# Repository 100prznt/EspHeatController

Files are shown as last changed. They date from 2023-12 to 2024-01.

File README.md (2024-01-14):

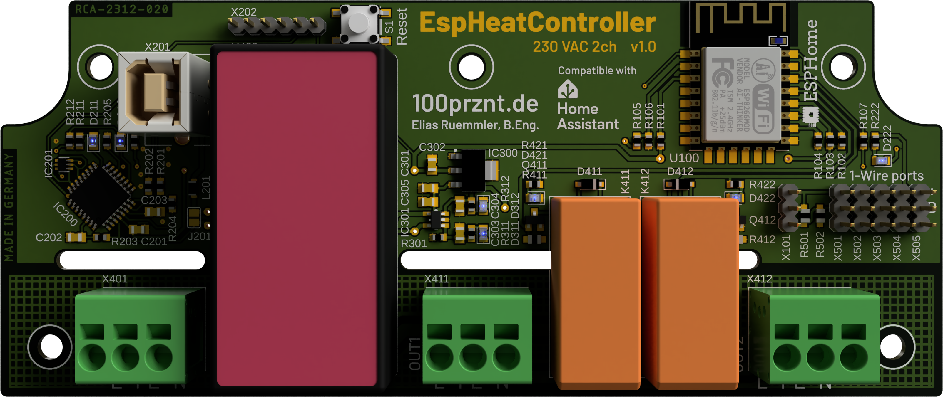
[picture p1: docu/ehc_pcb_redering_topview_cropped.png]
CAD rendering EspHeatController PCB


# HeatController
Bang-bang heat controller with 2 channels. ESP8266 based and compatible with Home Assistant.

## Specs
- ESP8266MOD (ESP-12-F)
- Onboard USB-UART bridge (FTDI)
- 230 VAC power supply with higher isolation voltage (for use in wet environment)
- Automatic switching of the power supply between USB and AC power
- Fully compatible with ESPHome and Home Assistant
- 2 output channels (230 VAC max. 10 A)
- 5 header for DS18B20 1-Wire temperature sensors
- Header for analog input

## Assembly
The PCB fits into a [Spelsberg TG PC 1612-9-to](https://www.spelsberg.de/industrieleergehaeuse/glatt-mit-befestigungsnocken/20100701/) enclosure. There is lots of space for the 230 V wiring in the lower area. I have installed PowerCon sockets from Neutrik here and M8 sockets for the DS818B20 sensors.

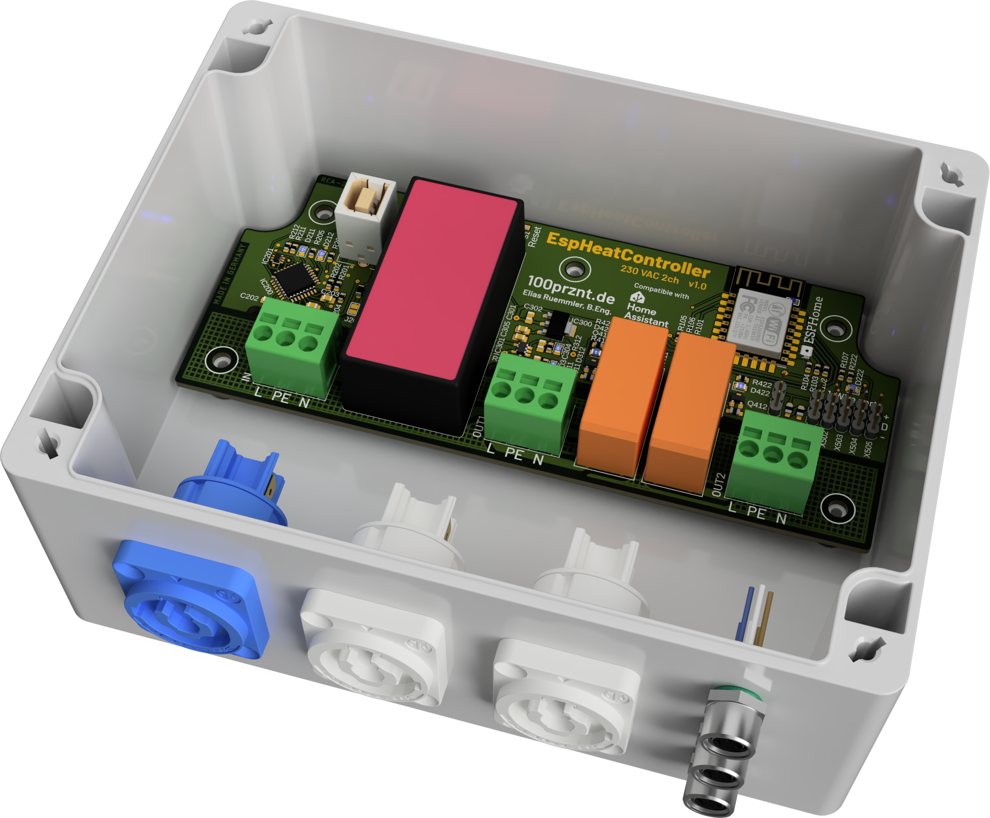
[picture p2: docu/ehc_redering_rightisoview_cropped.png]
CAD rendering EspHeatController


## Home Assistant

### Dashboard
The initial use of the __EspHeatController__ for me was as a frost watcher in addition to a pipe heating system. I created a separate dashboard in Home Assistant for this use case.

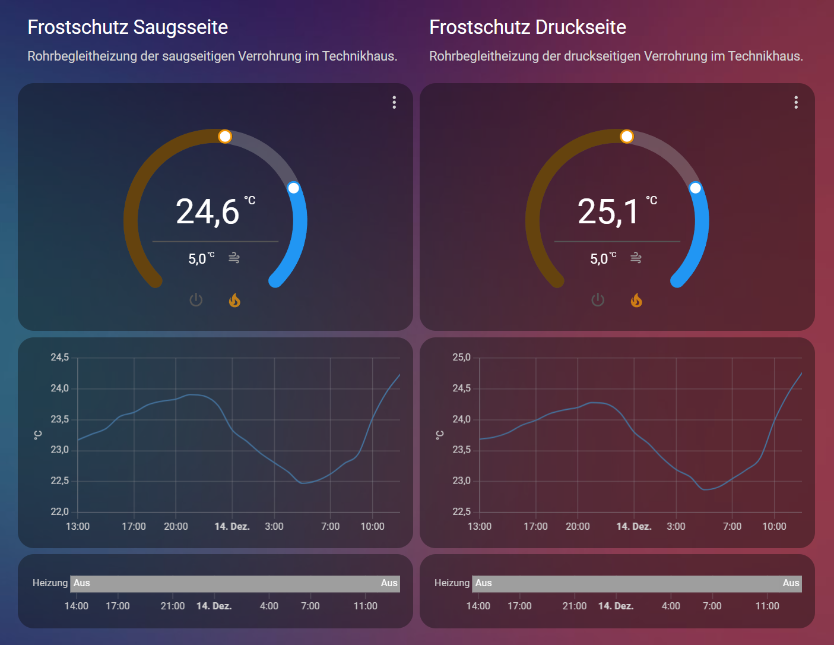
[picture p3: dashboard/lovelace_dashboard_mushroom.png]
Dashbord for the EspHeatController


You can find the configuration for this dashboard here:

* [dashboard/lovelace_ehc_config.yaml](dashboard/lovelace_ehc_config.yaml)

The following HACS extensions are required for this dashboard:

* [Mushroom](https://github.com/piitaya/lovelace-mushroom)
* [UI Card for Better Thermostat](https://github.com/KartoffelToby/better-thermostat-ui-card)

## Usage
As mentioned above, I use the __EspHeatController__ as a frost protector, the ESPHome config [esphome_ehc_config.yaml](esphome_ehc_config.yaml) implements a bang-bang controller for this. Alternatively, the hardware can be configured as a thermostat. It is also possible to control a cooling system in addition to the heater using the two switching channels.

## Function and description

### Datasheets
* [FTDI FT232BL](https://ftdichip.com/wp-content/uploads/2020/08/DS_FT232BL_BQ.pdf)
* [STMicroelectronics LD1117S](http://www.st.com/content/ccc/resource/technical/document/datasheet/99/3b/7d/91/91/51/4b/be/CD00000544.pdf/files/CD00000544.pdf/jcr:content/translations/en.CD0000054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)
* [TI TPS2104](https://www.ti.com/lit/gpn/tps2104)
* [Rohm UMH3N](https://fscdn.rohm.com/en/products/databook/datasheet/discrete/transistor/digital/umh3ntn-e.pdf)
* [AI Thinker ESP8266MOD](https://docs.ai-thinker.com/_media/esp8266/docs/esp-12f_product_specification_en.pdf)

## Hardware Versions
See [versions.md](versions.md) for hardware version details.

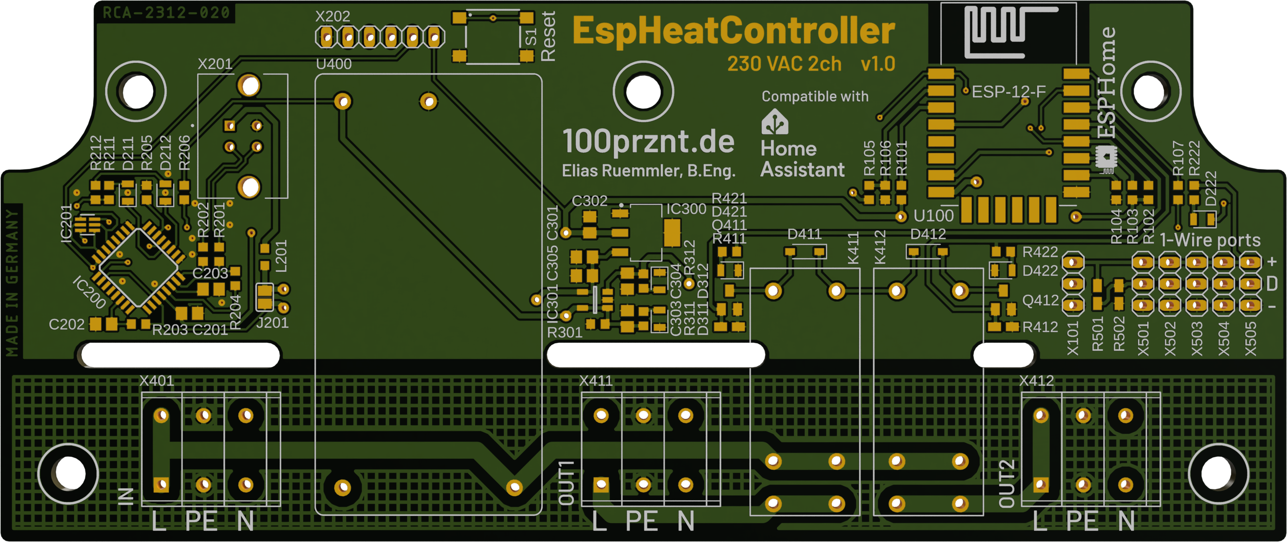
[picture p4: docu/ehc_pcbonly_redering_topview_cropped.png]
CAD rendering EspHeatController PCB w/o packages


### Known bugs in HW rev. v1.0
* [ ] Different resistor packages (R0603 vs. R0805W)
* [ ] IC301 invalide function table for USB power only
* [ ] IC300 (LD1117S) thermal != gnd
* [ ] IC200 (FT232BL) logiclevel for RST pin must be 5 V

### Features for next version
Features for new hardware versions.

* [ ] Onboard temperature sensor
* [ ] X202: Use stadard FTDI header pin assigment ([Datasheet TTL-232R](https://ftdichip.com/wp-content/uploads/2023/07/DS_TTL-232R_CABLES.pdf))
* [ ] Hardware lock between both relays (to use as 2-way motor switch)
* [ ] Hardware lock for the relays in boot state (check an [IO expander](https://esphome.io/#miscellaneous-components))
* [ ] Expand space between PE and GND
* [ ] Testpins for 5 V power supply
* [ ] Change FT232BL to [FT232RNL](https://ftdichip.com/wp-content/uploads/2023/03/DS_FT232RN.pdf) or external programmer

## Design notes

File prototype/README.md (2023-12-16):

# 1st Prototype

The idea to create the __EspHeatController__ was born out of necessity. Unexpectedly, winter was just around the corner and the pool water pipes were in risk of freezing. So the first __EspHeatController__ was created from the storage box.

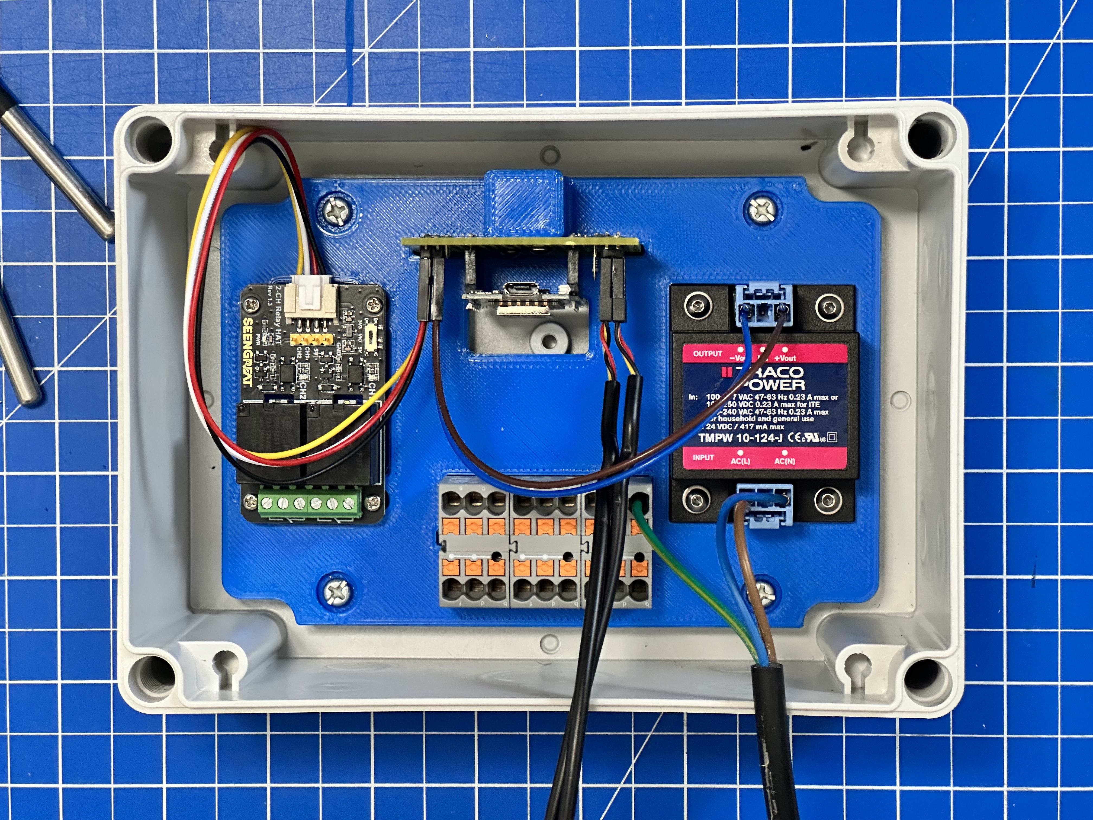
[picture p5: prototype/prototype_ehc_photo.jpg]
Prototype of the 1st EspHeatController


## BOM
* [Wemos - D1 mini](https://amzn.to/48l3Jik)
* [Seengreat - 2ch Relay Modul](https://amzn.to/3TtgmDJ) 3.3 / 5 V version
* [DS18B20 Sensor](https://amzn.to/48bSDw8)
* [Traco Power - TMP 10-105-J](https://www.tracopower.com/de/deu/model/tmpw-10-105-j)
* [3d printed mounting plate](Einsatz_TK_PC_1813_11_tm.stl)

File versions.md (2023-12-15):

# v1.0
- Initial version
- 1st PCBs ordered on December 15, 2023

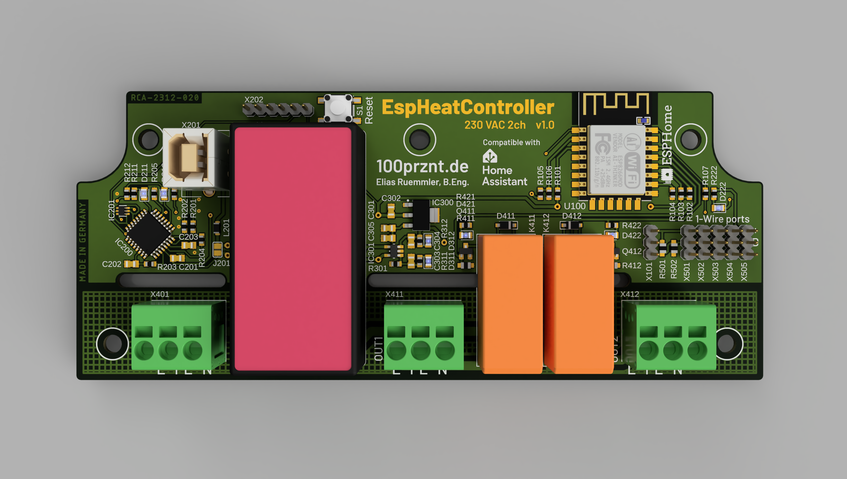
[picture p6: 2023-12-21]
docu/ehc_pcb_redering_topview.png

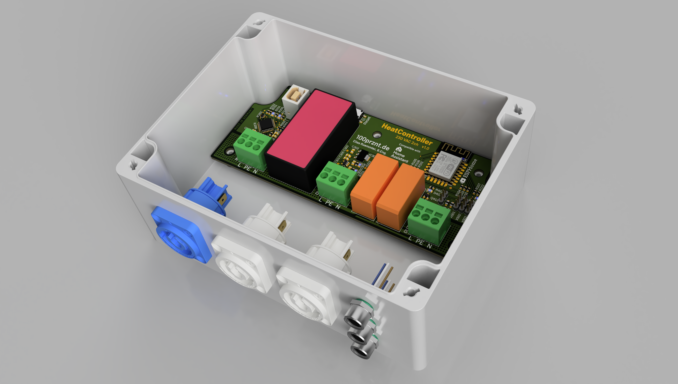
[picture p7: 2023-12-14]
docu/ehc_redering_rightisoview.png

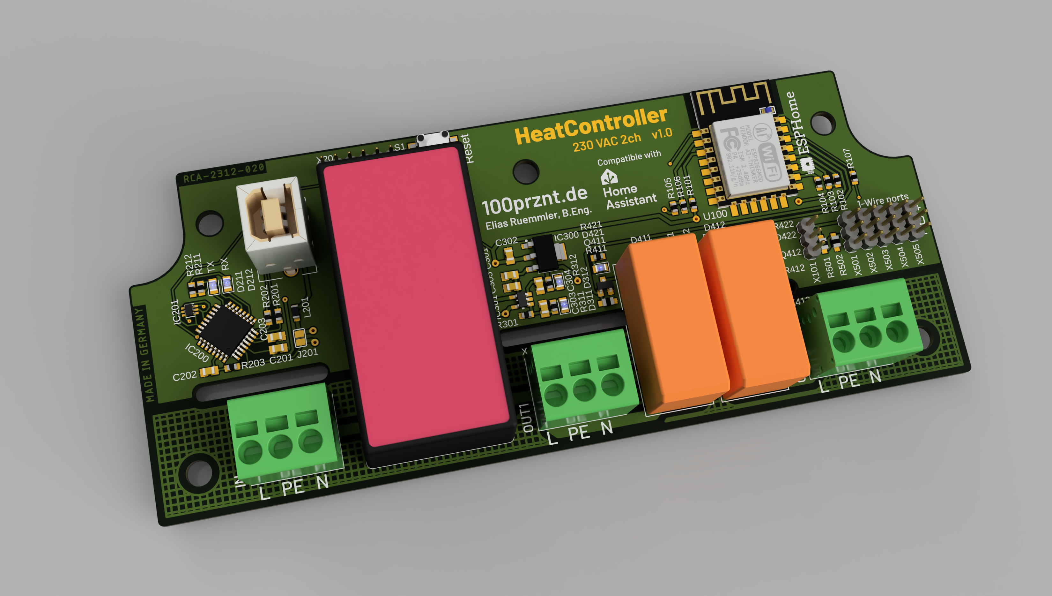
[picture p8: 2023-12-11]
docu/ehc_pcb_redering_leftisoview.png

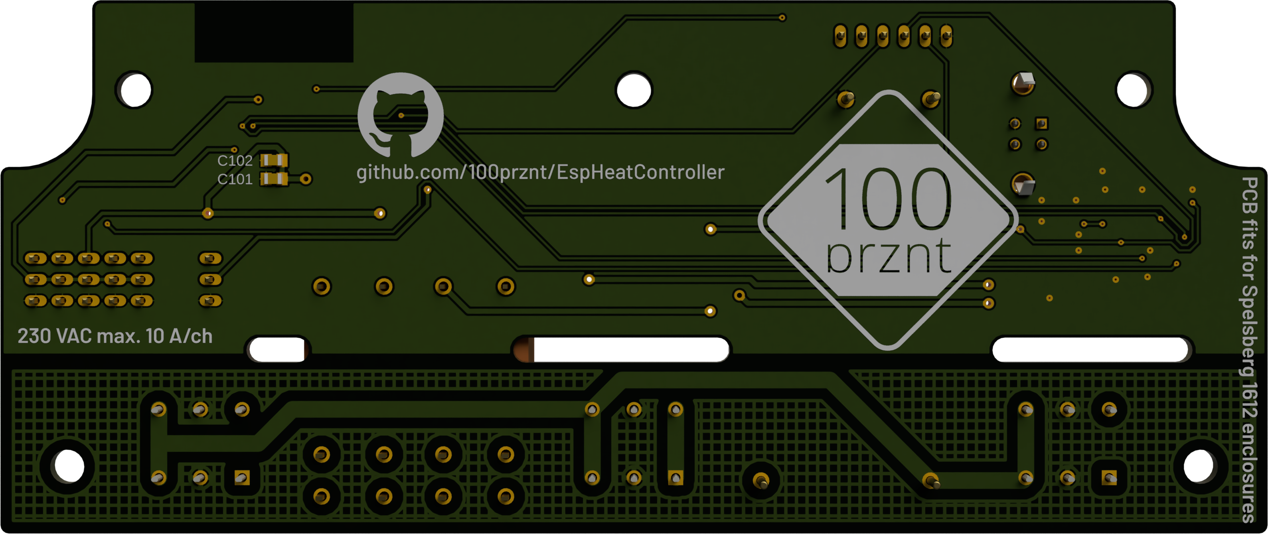
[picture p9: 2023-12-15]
docu/ehc_pcb_redering_bottomview_cropped.png

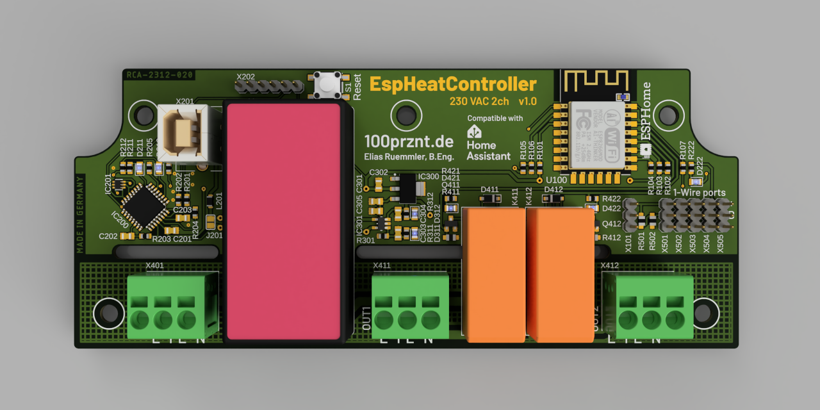
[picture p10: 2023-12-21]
docu/repo_image_ehc.png

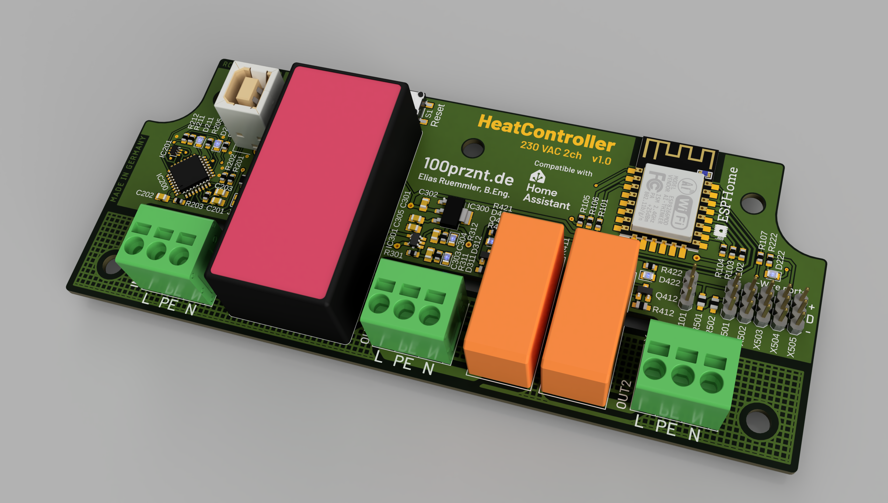
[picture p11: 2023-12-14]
docu/ehc_pcb_redering_rightisoview.png

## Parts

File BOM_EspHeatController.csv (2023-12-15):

Part | Value | Device | Package | Description | STORAGE_RCA | ORDER | CATEGORY | COLOR | DATASHEET-URL | DESCRIPTION.1 | MANUFACTURER | MANUFACTURER_PART_NUMBER | MOUSER_PART_NUMBER | RS_PART_NUMBER | FARNELL_PART_NUMBER | SERIES | VALUE.1
E001 | TG PC 1612-9-to |  |  | Enclosure | FALSCH | WAHR |  |  | https://www.spelsberg.de/industrieleergehaeuse/glatt-mit-befestigungsnocken.download?file=20100701.pdf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 |  | G�nther Spelsberg GmbH + Co. KG | 20100701
C101 |  | C-EUC0805 | C0805 | CAPACITOR, European symbol | WAHR
C102 |  | C-EUC0805 | C0805 | CAPACITOR, European symbol | WAHR
C201 | 100n | C-EUC0805 | C0805 | CAPACITOR, European symbol | WAHR
C202 | 100n | C-EUC0805 | C0805 | CAPACITOR, European symbol | WAHR
C203 | 33n | C-EUC0805 | C0805 | CAPACITOR, European symbol | WAHR
C301 | 100n | C-EUC0805 | C0805 | CAPACITOR, European symbol | WAHR
C302 | 10u | C-EUC0805 | C0805 | CAPACITOR, European symbol | WAHR
C303 | 0u22 | C-EUC0805 | C0805 | CAPACITOR, European symbol | WAHR
C304 | 0u22 | C-EUC0805 | C0805 | CAPACITOR, European symbol | WAHR
C305 | 1u | C-EUC0805 | C0805 | CAPACITOR, European symbol | WAHR
D211 | LED_BLUE | CHIP-FLAT-B_0805 | LEDC2012X110N_FLAT-B |  | FALSCH | WAHR | LED | BLUE |  | CHIP LED FLAT |  |  |  |  |  |  | LED_BLUE
D212 | LED_BLUE | CHIP-FLAT-B_0805 | LEDC2012X110N_FLAT-B |  | WAHR |  | LED | BLUE |  | CHIP LED FLAT |  |  |  |  |  |  | LED_BLUE
D222 | LED_BLUE | CHIP-FLAT-B_0805 | LEDC2012X110N_FLAT-B |  | WAHR |  | LED | BLUE |  | CHIP LED FLAT |  |  |  |  |  |  | LED_BLUE
D311 | LED_BLUE | CHIP-FLAT-B_0805 | LEDC2012X110N_FLAT-B |  | WAHR |  | LED | BLUE |  | CHIP LED FLAT |  |  |  |  |  |  | LED_BLUE
D312 | LED_BLUE | CHIP-FLAT-B_0805 | LEDC2012X110N_FLAT-B |  | WAHR |  | LED | BLUE |  | CHIP LED FLAT |  |  |  |  |  |  | LED_BLUE
D411 | 1N4148W | DIODE_1N4148W-7-F_SOD123G | SOD3715X135 | Diode Rectifier - Popular parts | FALSCH | WAHR | Diode |  |  | DIODE GEN PURP 100V 300MA SOD123 | Diodes Incorporated |  |  |  | 2675147 |  | 1N4148W
D412 | 1N4148W | DIODE_1N4148W-7-F_SOD123G | SOD3715X135 | Diode Rectifier - Popular parts | FALSCH | WAHR | Diode |  |  | DIODE GEN PURP 100V 300MA SOD123 | Diodes Incorporated |  |  |  | 2675147 |  | 1N4148W
D421 | LED_BLUE | CHIP-FLAT-B_0805 | LEDC2012X110N_FLAT-B |  | WAHR |  | LED | BLUE |  | CHIP LED FLAT |  |  |  |  |  |  | LED_BLUE
D422 | LED_BLUE | CHIP-FLAT-B_0805 | LEDC2012X110N_FLAT-B |  | WAHR |  | LED | BLUE |  | CHIP LED FLAT |  |  |  |  |  |  | LED_BLUE
IC200 | FT232BL | FT232BL | LQFP32-7X7 | USB to serial UART interface | FALSCH | WAHR |  |  |  |  |  | FT232BL/TR
IC201 | UMH3N | UMH3NTNSOT-363_ROM | SOT-363_ROM |  | FALSCH | WAHR |  |  |  |  | ROHM Semiconductor | UMH3NTN |  |  | 1680404
IC300 | LD1117S33TR | LD1117_SOT223 | SOT230P700X170-4 | Adjustable and fixed positive voltage regulator | FALSCH | WAHR | IC_Linear |  |  | Adjustable voltage regulator | STMicroelectronics | LD1117S50TR |  | 686-9379 |  | LM1117
IC301 | TPS2104DBVR | TPS2104DBVRDBV0005A_M | DBV0005A_M |  | FALSCH |  |  |  |  | TPS2104DBVR | Texas Instruments | TPS2104DBVR
J201 |  | SJ | SJ | SMD solder JUMPER | WAHR
K411 | RZ03-1A4-D005 | 1-1415899-6 | RELAY-SPST2_5MM |  | FALSCH | WAHR | Power Relays |  |  | RZ03-1A4-D012 | TE Connectivity | 1-1415899-6 |  |  |  | SCHRACK Power PCB Relay RZ
K412 | RZ03-1A4-D005 | 1-1415899-6 | RELAY-SPST2_5MM |  | FALSCH | WAHR | Power Relays |  |  | RZ03-1A4-D012 | TE Connectivity | 1-1415899-6 |  |  |  | SCHRACK Power PCB Relay RZ
L201 | MH2029-400Y | L-EUL2012C | L2012C | INDUCTOR, European symbol | FALSCH | WAHR |  |  |  | MH2029-400Y | Bourns | MH2029-400Y |  |  | 2859028
Q411 | BSS138 | NMOSFETSOT23-GSD | SOT23 | N-Channel MOSFET - Generic | FALSCH | WAHR | Transistor |  |  |  |  |  |  |  | 2323154 |  | NMOSFET
Q412 | BSS138 | NMOSFETSOT23-GSD | SOT23 | N-Channel MOSFET - Generic | FALSCH | WAHR | Transistor |  |  |  |  |  |  |  |  |  | NMOSFET
R101 | 12k | R-EU_R0603 | R0603 | RESISTOR, European symbol | WAHR
R102 | 12k | R-EU_R0603 | R0603 | RESISTOR, European symbol | WAHR
R103 | 12k | R-EU_R0603 | R0603 | RESISTOR, European symbol | WAHR
R104 | 12k | R-EU_R0603 | R0603 | RESISTOR, European symbol | WAHR
R105 | n/a | R-EU_R0603 | R0603 | RESISTOR, European symbol | WAHR
R106 | n/a | R-EU_R0603 | R0603 | RESISTOR, European symbol | WAHR
R107 | 470 | R-EU_R0603 | R0603 | RESISTOR, European symbol | WAHR
R201 | 27R | R-EU_R0603 | R0603 | RESISTOR, European symbol | WAHR
R202 | 27R | R-EU_R0603 | R0603 | RESISTOR, European symbol | WAHR
R203 | 470 | R-EU_R0603 | R0603 | RESISTOR, European symbol | WAHR
R204 | 1K5 | R-EU_R0603 | R0603 | RESISTOR, European symbol | WAHR
R205 | 10K | R-EU_R0603 | R0603 | RESISTOR, European symbol | WAHR
R206 | 1K5 | R-EU_R0603 | R0603 | RESISTOR, European symbol | WAHR
R211 | 220 | R-EU_R0603 | R0603 | RESISTOR, European symbol | WAHR
R212 | 220 | R-EU_R0603 | R0603 | RESISTOR, European symbol | WAHR
R222 | 220 | R-EU_R0603 | R0603 | RESISTOR, European symbol | WAHR
R301 | 10k | R-EU_R0603 | R0603 | RESISTOR, European symbol | WAHR
R311 | 500R | R-EU_R0603 | R0603 | RESISTOR, European symbol | WAHR
R312 | 500R | R-EU_R0603 | R0603 | RESISTOR, European symbol | WAHR
R411 | 47K | R-EU_R0805W | R0805W | RESISTOR, European symbol | WAHR
R412 | 47K | R-EU_R0805W | R0805W | RESISTOR, European symbol | WAHR
R421 | 220 | R-EU_R0603 | R0603 | RESISTOR, European symbol | WAHR
R422 | 220 | R-EU_R0603 | R0603 | RESISTOR, European symbol | WAHR
R501 | 4K7 | R-EU_R0805W | R0805W | RESISTOR, European symbol | WAHR
R502 | n/a | R-EU_R0805W | R0805W | RESISTOR, European symbol | WAHR
S1 | 430152050826 | 430152050826 |  | WS-TASV SMT Tact Switch 6x6 mm | FALSCH | WAHR |  |  | https://www.we-online.com/redexpert/spec/430152050826?ae |  |  | 430152050826 |  |  | 2065110 |  | 430152050826
U100 | ESP8266MOD | ESP8266MOD | ESP12F-SMD |  | WAHR
U400 | TMF 10105 | TMF_101 | TMF10 |  | FALSCH | WAHR |  |  |  |  |  |  |  |  | 2829604
X101 |  | PINHD-1X3 | 1X03 | PIN HEADER | WAHR
X201 | M701-330442 | M701-330442 | M701-330442 | USB(2.0) Type-B, RCPT, 4POS, THT-VERT | FALSCH | WAHR | Connector |  |  | CONN RCPT USB2.0 TYPEB 4POS VERT | Harwin | M701-330442 |  |  | 2751680
X202 |  | PINHD-1X6 | 1X06 | PIN HEADER | WAHR
X401 | SPT2,5/3-V-5,0 | SPT2,5/3-V-5,0 | SPT2,5/3-V-5,0 | SPT 2,5/ 3-V-5,0 | FALSCH | WAHR |  |  |  | PCB terminal block, nominal current: 24 A, rated voltage (III/2): 400 V, nominal cross section: 2.5 mm?, Number of potentials: 3, Number of rows: 1, Number of positions per row: 3, product range: SPT 2,5/..-V, pitch: 5 mm, connection method: Push-in spring connection, mounting: Wave soldering, conductor/PCB connection direction: 90 ?, color: green, Pin layout: Linear double pinning, Solder pin [P]: 2.5 mm, type of packaging: packed in cardboard | Phoenix Contact | 1991105 | 651-1991105 |  | 2664565
X411 | SPT2,5/3-V-5,0 | SPT2,5/3-V-5,0 | SPT2,5/3-V-5,0 | SPT 2,5/ 3-V-5,0 | FALSCH | WAHR |  |  |  | PCB terminal block, nominal current: 24 A, rated voltage (III/2): 400 V, nominal cross section: 2.5 mm?, Number of potentials: 3, Number of rows: 1, Number of positions per row: 3, product range: SPT 2,5/..-V, pitch: 5 mm, connection method: Push-in spring connection, mounting: Wave soldering, conductor/PCB connection direction: 90 ?, color: green, Pin layout: Linear double pinning, Solder pin [P]: 2.5 mm, type of packaging: packed in cardboard | Phoenix Contact | 1991105 | 651-1991105 |  | 2664565
X412 | SPT2,5/3-V-5,0 | SPT2,5/3-V-5,0 | SPT2,5/3-V-5,0 | SPT 2,5/ 3-V-5,0 | FALSCH | WAHR |  |  |  | PCB terminal block, nominal current: 24 A, rated voltage (III/2): 400 V, nominal cross section: 2.5 mm?, Number of potentials: 3, Number of rows: 1, Number of positions per row: 3, product range: SPT 2,5/..-V, pitch: 5 mm, connection method: Push-in spring connection, mounting: Wave soldering, conductor/PCB connection direction: 90 ?, color: green, Pin layout: Linear double pinning, Solder pin [P]: 2.5 mm, type of packaging: packed in cardboard | Phoenix Contact | 1991105 | 651-1991105 |  | 2664565
X501 |  | PINHD-1X3 | 1X03 | PIN HEADER | WAHR
X502 |  | PINHD-1X3 | 1X03 | PIN HEADER | WAHR
X503 |  | PINHD-1X3 | 1X03 | PIN HEADER | WAHR
X504 |  | PINHD-1X3 | 1X03 | PIN HEADER | WAHR
X505 |  | PINHD-1X3 | 1X03 | PIN HEADER | WAHR

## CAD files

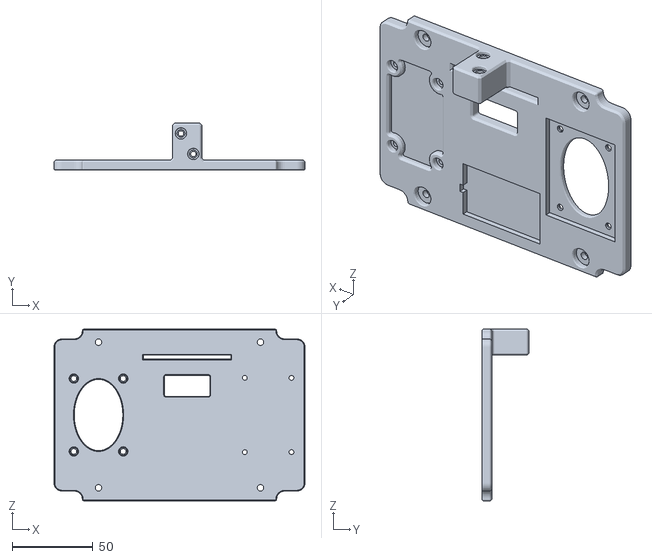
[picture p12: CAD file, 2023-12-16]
prototype/Einsatz_TK_PC_1813_11_tm.stl
155.0 x 28.9 x 106.0

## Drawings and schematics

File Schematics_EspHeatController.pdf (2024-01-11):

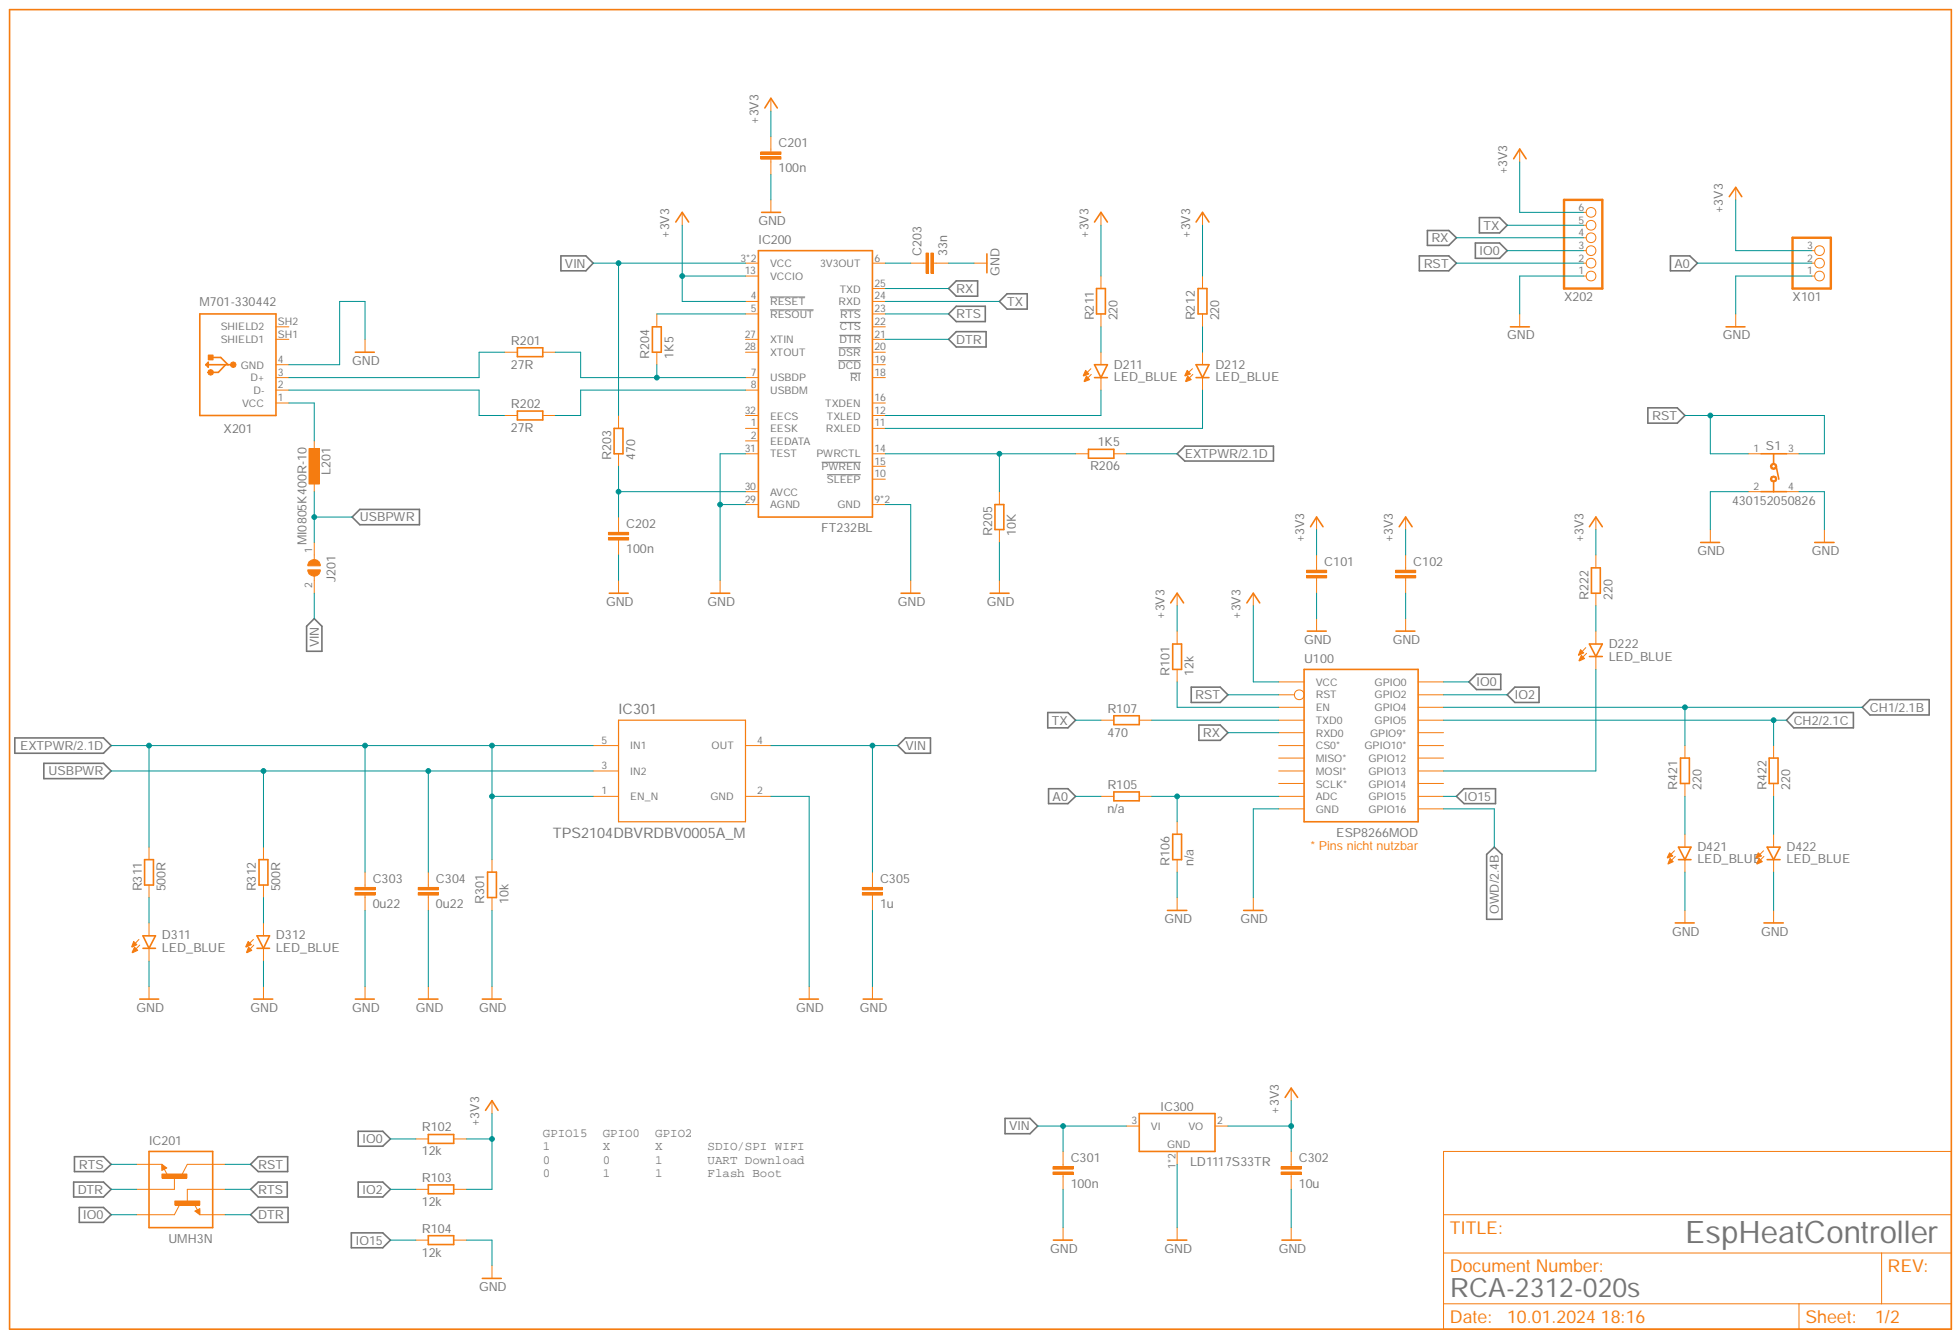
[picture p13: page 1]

Document Number: RCA-2312-020s | REV:

Date: 10.01.2024 18:16 | Sheet: 1/2

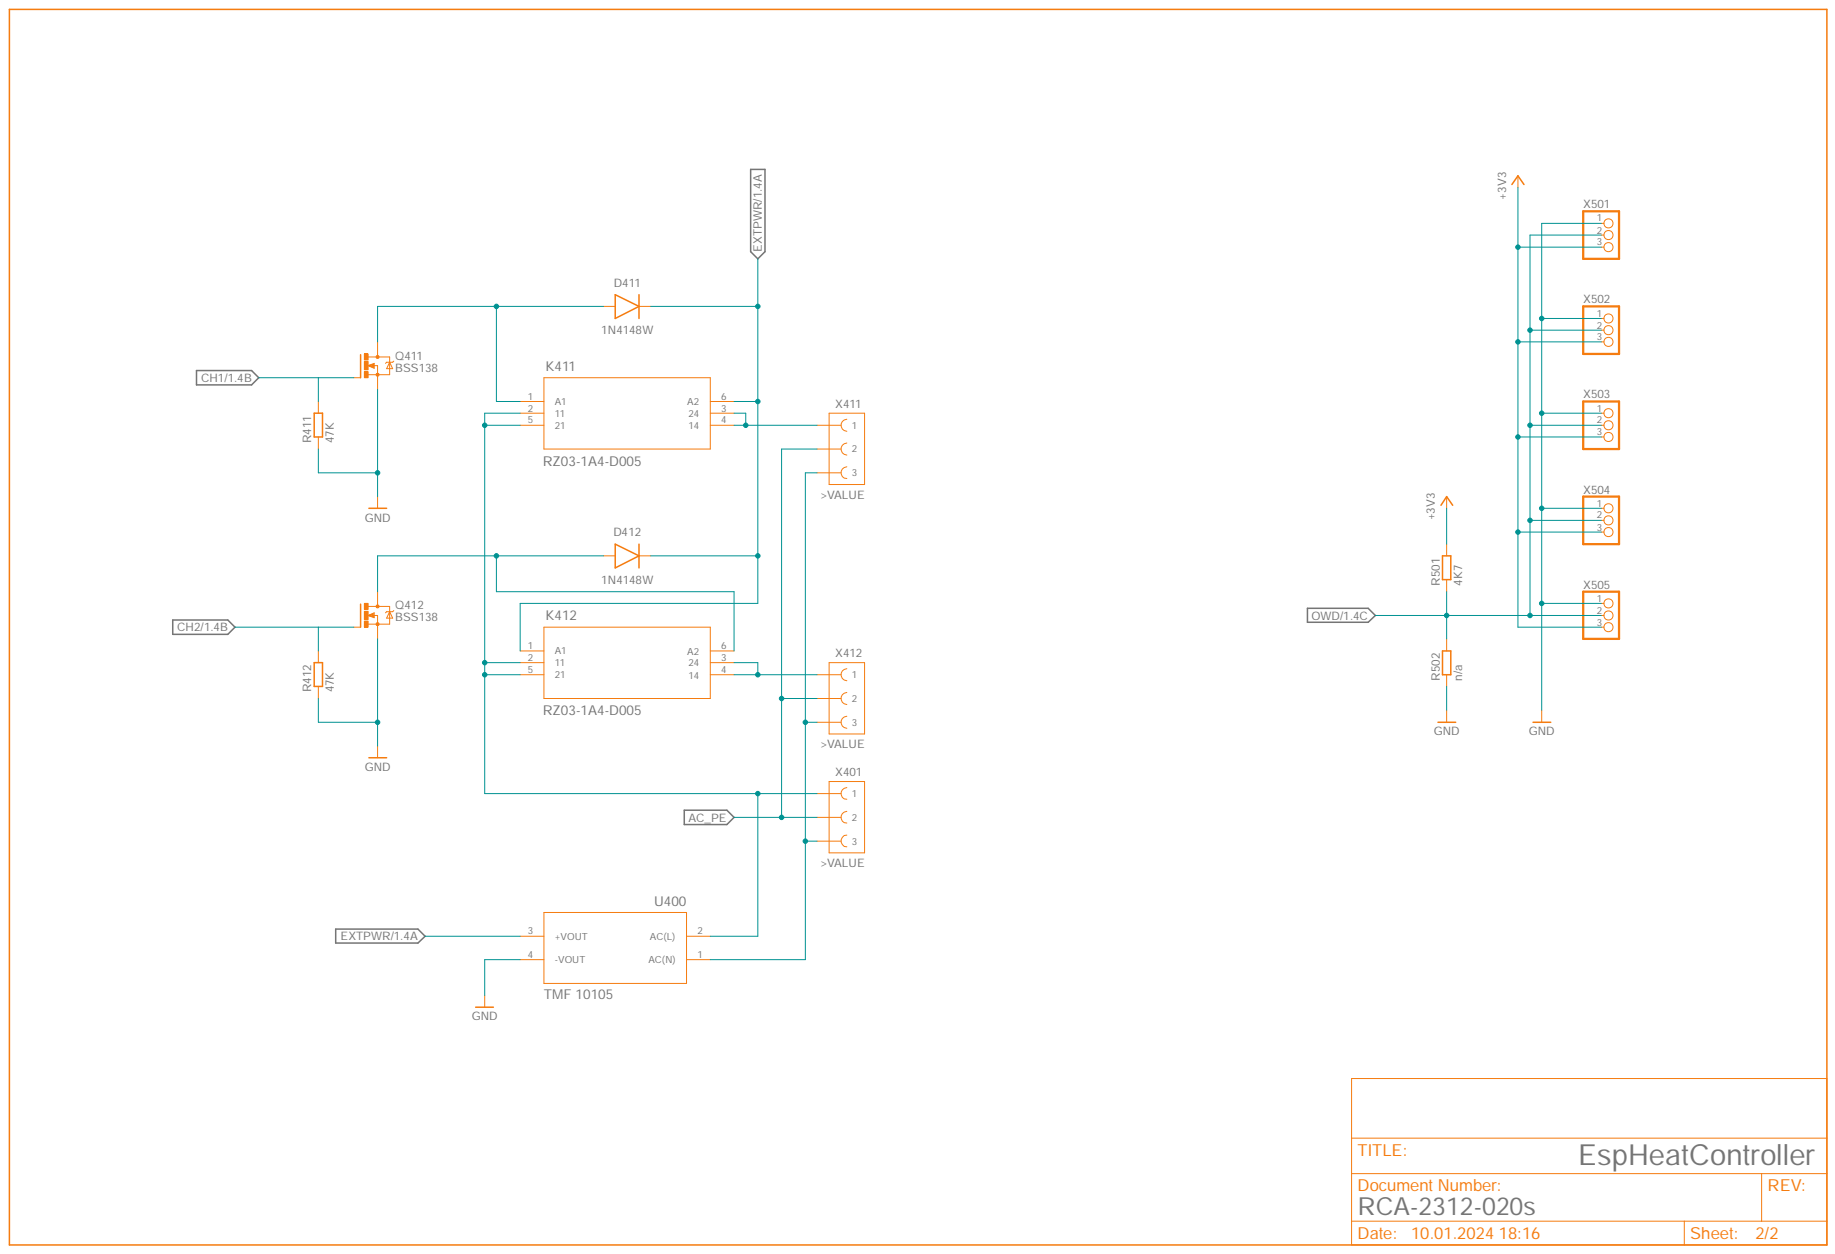
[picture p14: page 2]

Document Number: RCA-2312-020s | REV:

Date: 10.01.2024 18:16 | Sheet: 2/2

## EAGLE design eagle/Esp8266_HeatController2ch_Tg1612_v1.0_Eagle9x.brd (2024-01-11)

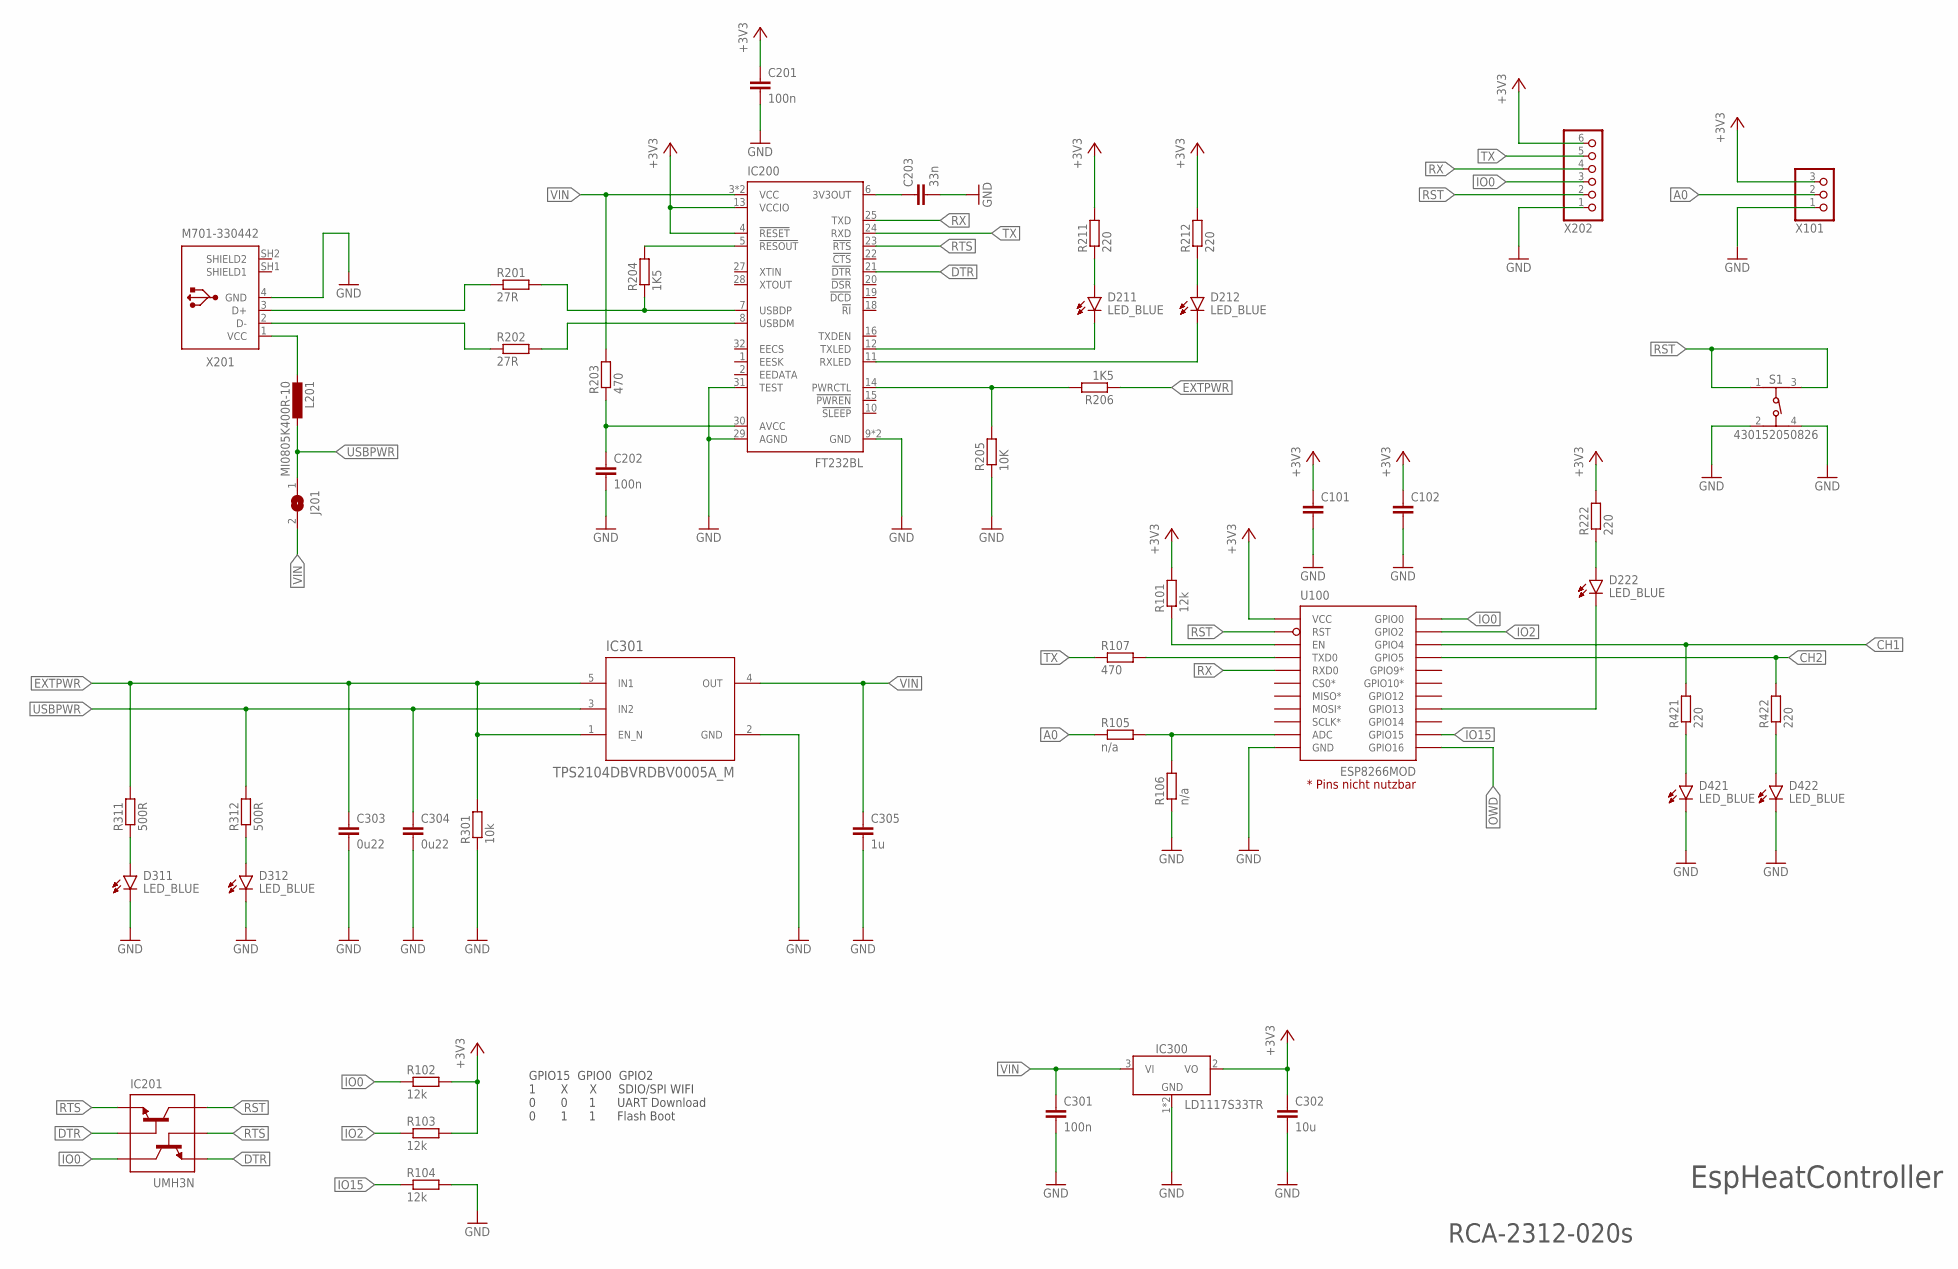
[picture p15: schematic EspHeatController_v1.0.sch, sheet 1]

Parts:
C101, C102: C-EUC0805; C0805
C201, C202, C301: 100n; C0805
C203: 33n; C0805
C302: 10u; C0805
C303, C304: 0u22; C0805
C305: 1u; C0805
D211, D212, D222, D311, D312, D421, D422: LED_BLUE; LEDC2012X110N_FLAT-B
IC200: FT232BL; LQFP32-7X7
IC201: UMH3N; SOT-363_ROM
IC300: LD1117S33TR; SOT230P700X170-4
IC301: TPS2104DBVRDBV0005A_M; DBV0005A_M
J201: SJ
L201: MI0805K400R-10; L2012C
R101, R102, R103, R104: 12k; R0603
R105, R106: n/a; R0603
R107, R203: 470; R0603
R201, R202: 27R; R0603
R204, R206: 1K5; R0603
R205: 10K; R0603
R211, R212, R222, R421, R422: 220; R0603
R301: 10k; R0603
R311, R312: 500R; R0603
S1: 430152050826
U100: ESP8266MOD; ESP12F-SMD
X101: PINHD-1X3; 1X03
X201: M701-330442
X202: PINHD-1X6; 1X06

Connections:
+3V3: C101.1, C102.1, C201.1, C302.1, IC200.4 (!RESET), IC200.13 (VCCIO), IC300.2 (VO), R101.2, R102.2, R103.2, R211.2, R212.2, R222.2, U100.VCC, X101.3, X202.6; also elsewhere on the board
A0: R105.1, X101.2
CH1: R421.2, U100.GPIO4; also elsewhere on the board
CH2: R422.2, U100.GPIO5; also elsewhere on the board
DTR: IC200.21 (!DTR), IC201.2 (B1), IC201.4 (E2)
D_N: IC200.8 (USBDM), R202.2
D_P: IC200.7 (USBDP), R201.2, R204.1
EXTPWR: C303.1, IC301.1 (EN_N), IC301.5 (IN1), R206.1, R301.2, R311.2; also elsewhere on the board
GND: C101.2, C102.2, C201.2, C202.2, C203.2, C301.2, C302.2, C303.2, C304.2, C305.2, D311.C, D312.C, D421.C, D422.C, IC200.9 (GND), IC200.17 (GND), IC200.29 (AGND), IC200.31 (TEST), IC300.1 (GND), IC300.4 (GND), IC301.2 (GND), R104.2, R106.1, R205.1, R301.1, S1.2, S1.4, U100.GND, X101.1, X201.4 (GND), X202.1; also elsewhere on the board
IO0: IC201.3 (C2), R102.1, U100.GPIO0, X202.3
IO2: R103.1, U100.GPIO2
IO15: R104.1, U100.GPIO15
unnamed: R105.2, R106.2, U100.ADC
unnamed: R107.2, U100.TXD0
unnamed: R101.1, U100.EN
unnamed: D211.C, IC200.12 (TXLED)
unnamed: C202.1, IC200.30 (AVCC), R203.1
unnamed: D212.C, IC200.11 (RXLED)
unnamed: D211.A, R211.1
unnamed: D212.A, R212.1
unnamed: C203.1, IC200.6 (3V3OUT)
unnamed: D312.A, R312.1
unnamed: D422.A, R422.1
unnamed: L201.2, X201.1 (VCC)
unnamed: D311.A, R311.1
unnamed: D421.A, R421.1
unnamed: IC200.5 (!RESOUT), R204.2
unnamed: IC200.14 (PWRCTL), R205.2, R206.2
unnamed: D222.C, U100.GPIO13
unnamed: D222.A, R222.1
OWD: U100.GPIO16; also elsewhere on the board
RST: IC201.6 (C1), S1.1, S1.3, U100.RST, X202.2
RTS: IC200.23 (!RTS), IC201.1 (E1), IC201.5 (B2)
RX: IC200.25 (TXD), U100.RXD0, X202.4
TX: IC200.24 (RXD), R107.1, X202.5
USBD_N: R202.1, X201.2 (D-)
USBD_P: R201.1, X201.3 (D+)
USBPWR: C304.1, IC301.3 (IN2), J201.1, L201.1, R312.2
VIN: C301.1, C305.1, IC200.3 (VCC), IC200.26 (VCC), IC300.3 (VI), IC301.4 (OUT), J201.2, R203.2

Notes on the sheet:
GPIO15 GPIO0 GPIO2 1 X X SDIO/SPI WIFI 0 0 1 UART Download 0 1 1 Flash Boot
RCA-2312-020s
EspHeatController

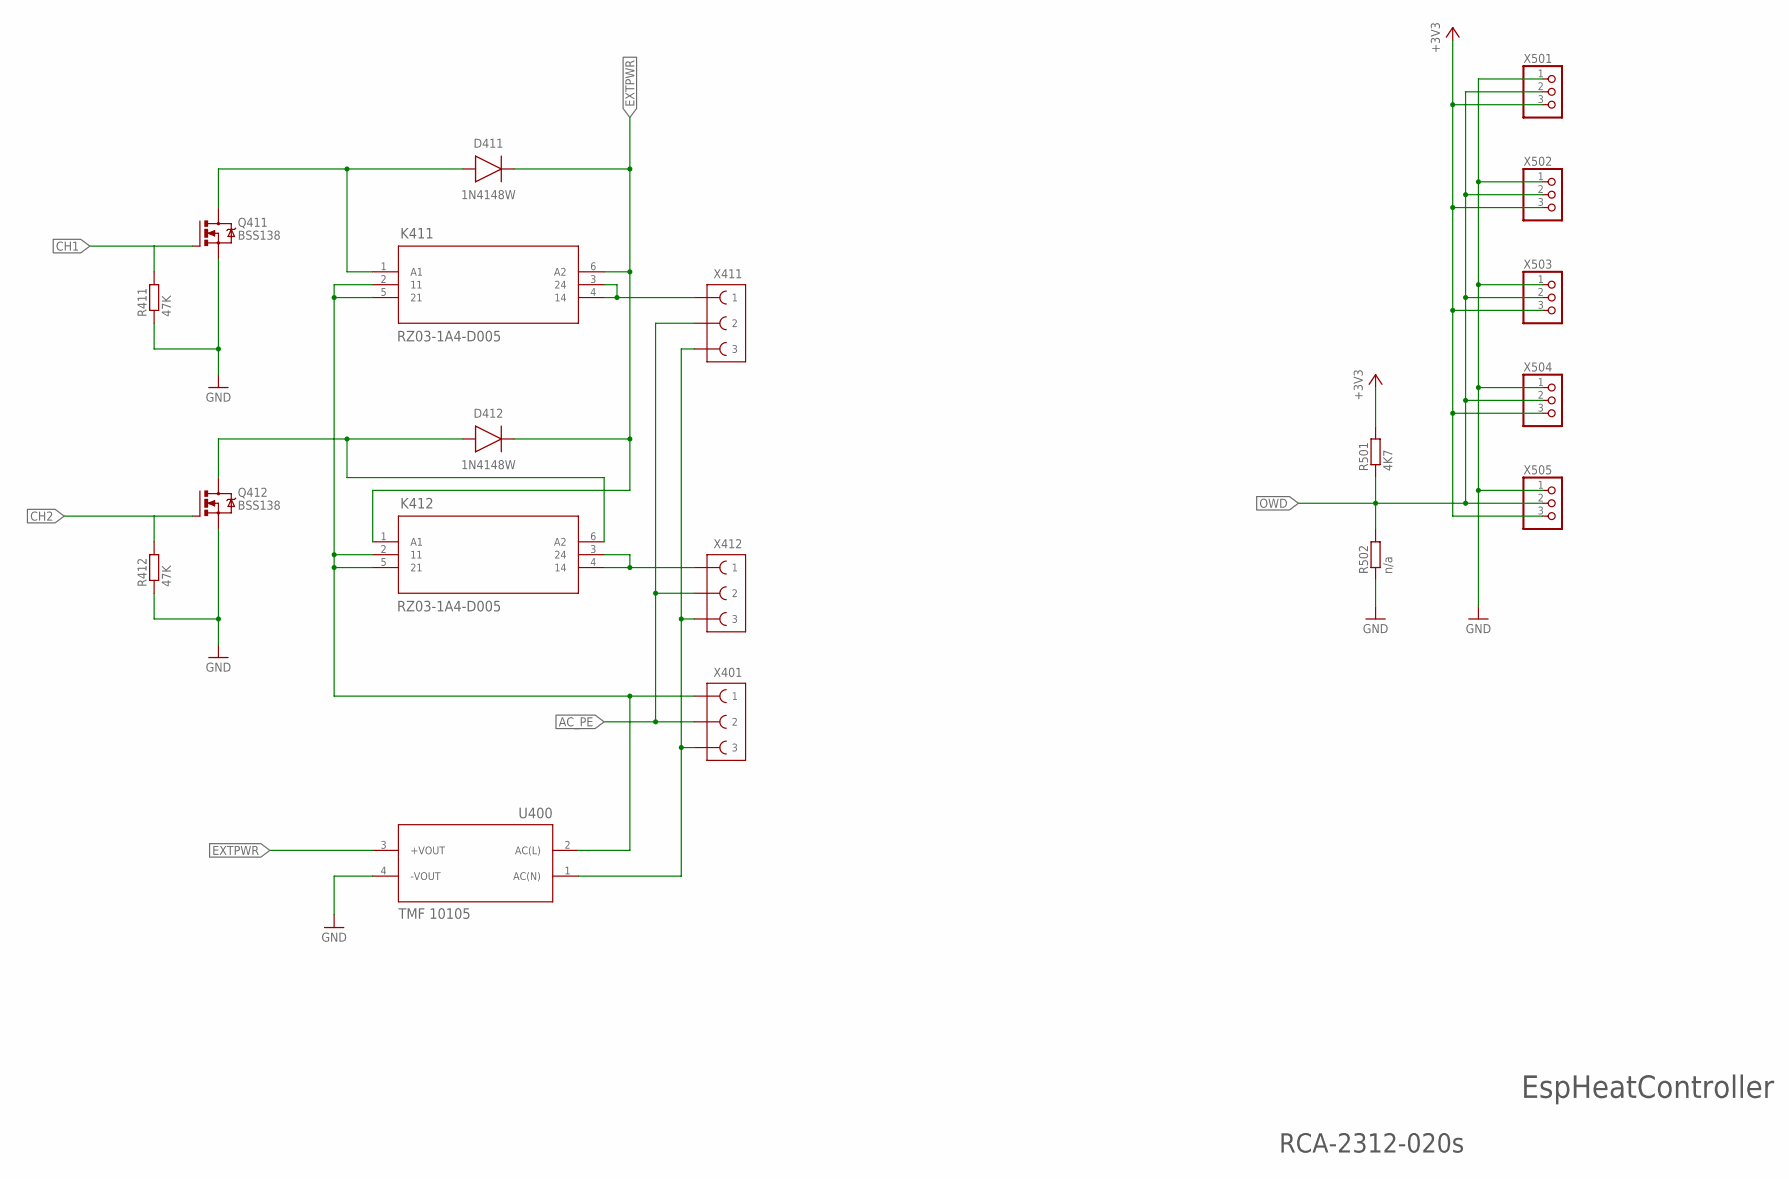
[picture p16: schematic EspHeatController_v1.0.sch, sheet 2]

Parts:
D411, D412: 1N4148W; SOD3715X135
K411, K412: RZ03-1A4-D005; RELAY-SPST2_5MM
Q411, Q412: BSS138; SOT23
R411, R412: 47K; R0805W
R501: 4K7; R0805W
R502: n/a; R0805W
U400: TMF 10105; TMF10
X401, X411, X412: SPT2,5/3-V-5,0
X501, X502, X503, X504, X505: PINHD-1X3; 1X03

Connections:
+3V3: R501.2, X501.3, X502.3, X503.3, X504.3, X505.3; also elsewhere on the board
AC_L: K411.2 (11), K411.5 (21), K412.2 (11), K412.5 (21), U400.2 (AC(L)), X401.1A (1), X401.1B (1)
AC_N: U400.1 (AC(N)), X401.3A (3), X401.3B (3), X411.3A (3), X411.3B (3), X412.3A (3), X412.3B (3)
AC_PE: X401.2A (2), X401.2B (2), X411.2A (2), X411.2B (2), X412.2A (2), X412.2B (2)
CH1: Q411.1 (G), R411.2; also elsewhere on the board
CH2: Q412.1 (G), R412.2; also elsewhere on the board
EXTPWR: D411.1 (C), D412.1 (C), K411.6 (A2), K412.1 (A1), U400.3 (+VOUT); also elsewhere on the board
GND: Q411.2 (S), Q412.2 (S), R411.1, R412.1, R502.1, U400.4 (-VOUT), X501.1, X502.1, X503.1, X504.1, X505.1; also elsewhere on the board
unnamed: D412.2 (A), K412.6 (A2), Q412.3 (D)
unnamed: D411.2 (A), K411.1 (A1), Q411.3 (D)
unnamed: K411.3 (24), K411.4 (14), X411.1A (1), X411.1B (1)
unnamed: K412.3 (24), K412.4 (14), X412.1A (1), X412.1B (1)
OWD: R501.1, R502.2, X501.2, X502.2, X503.2, X504.2, X505.2; also elsewhere on the board

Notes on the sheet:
EspHeatController
RCA-2312-020s

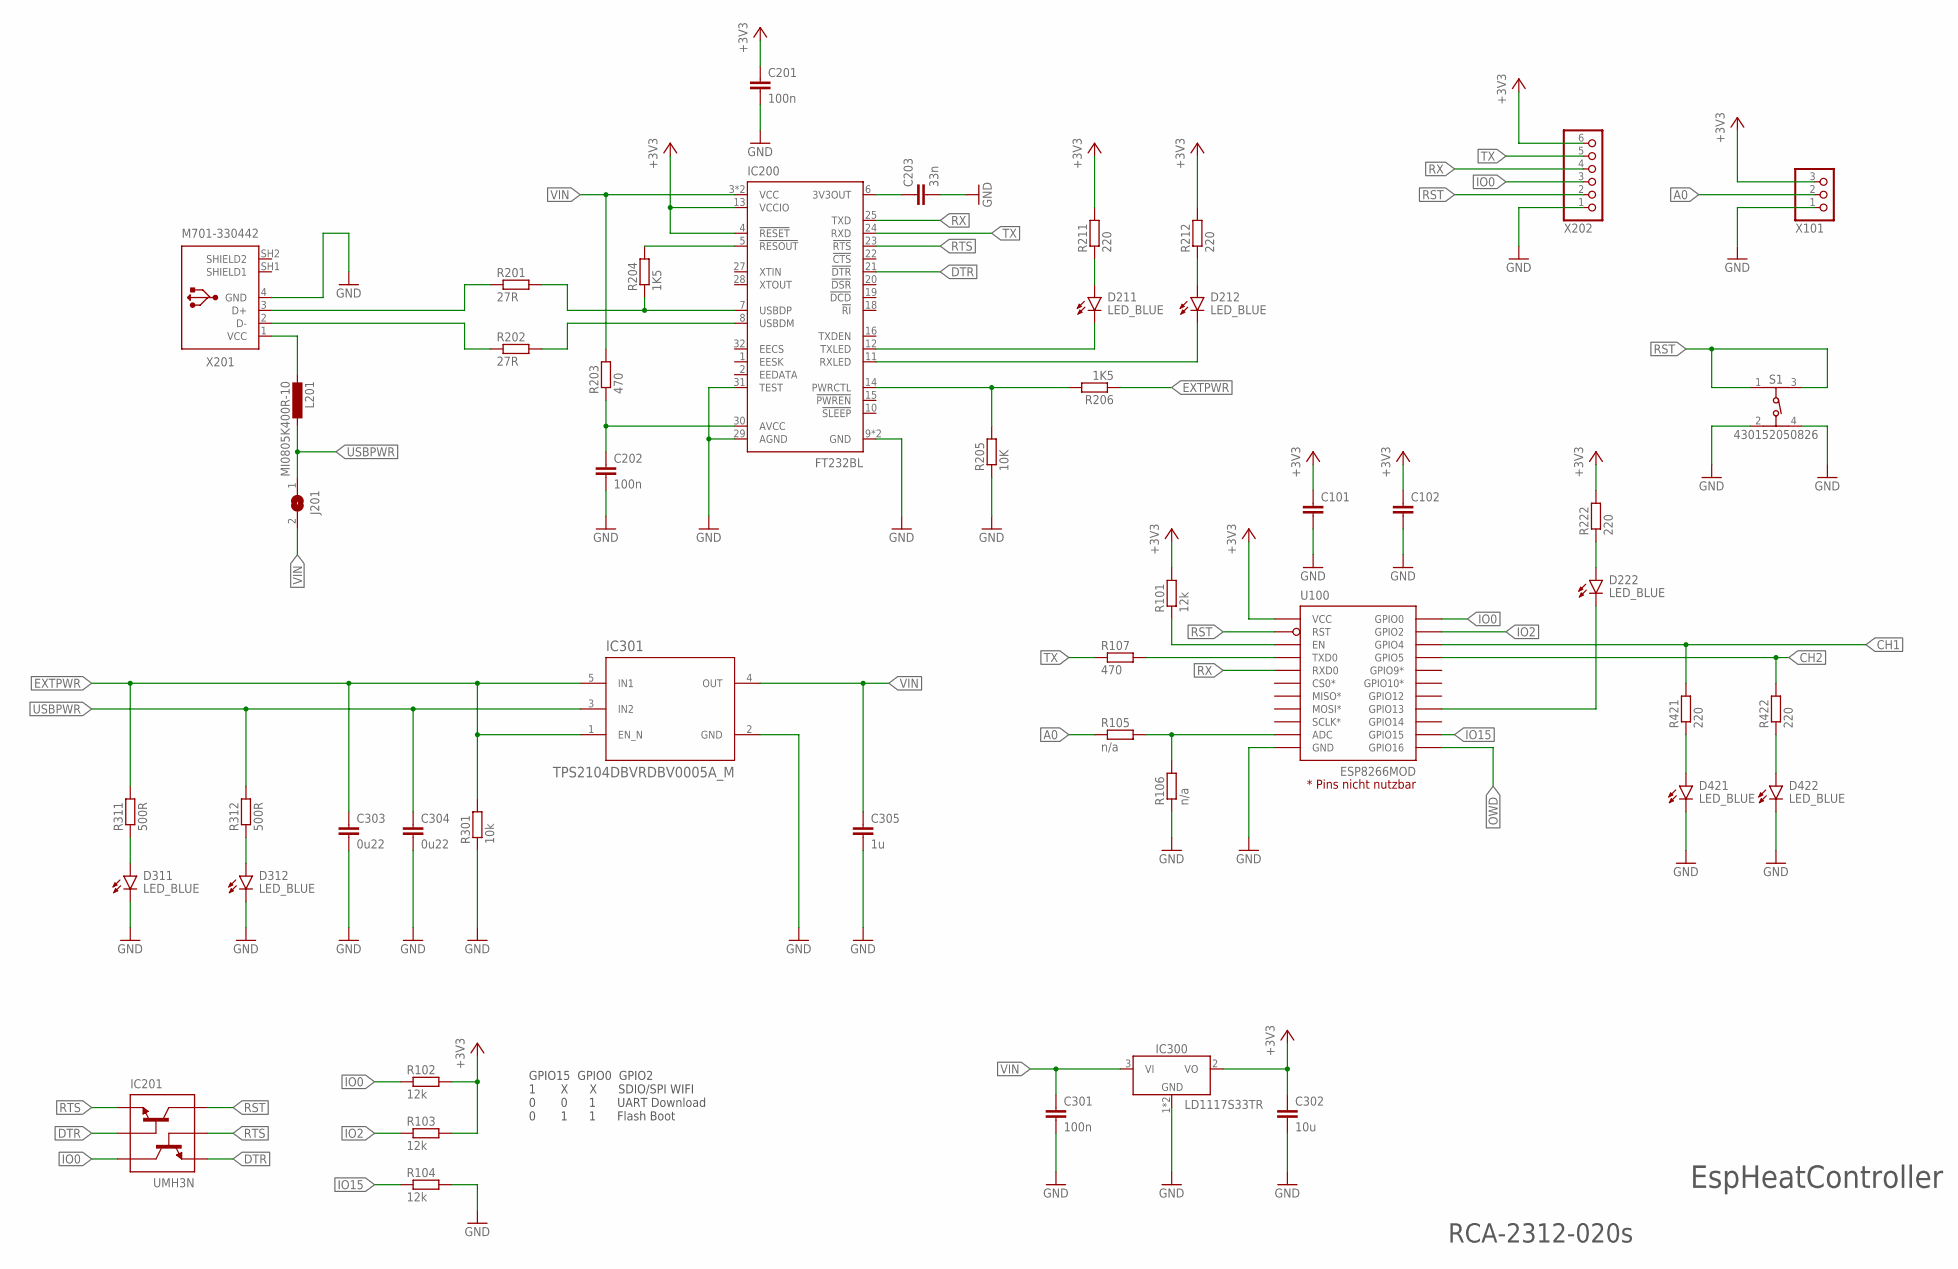
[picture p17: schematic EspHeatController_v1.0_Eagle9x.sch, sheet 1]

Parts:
C101, C102: C-EUC0805; C0805
C201, C202, C301: 100n; C0805
C203: 33n; C0805
C302: 10u; C0805
C303, C304: 0u22; C0805
C305: 1u; C0805
D211, D212, D222, D311, D312, D421, D422: LED_BLUE; LEDC2012X110N_FLAT-B
IC200: FT232BL; LQFP32-7X7
IC201: UMH3N; SOT-363_ROM
IC300: LD1117S33TR; SOT230P700X170-4
IC301: TPS2104DBVRDBV0005A_M; DBV0005A_M
J201: SJ
L201: MI0805K400R-10; L2012C
R101, R102, R103, R104: 12k; R0603
R105, R106: n/a; R0603
R107, R203: 470; R0603
R201, R202: 27R; R0603
R204, R206: 1K5; R0603
R205: 10K; R0603
R211, R212, R222, R421, R422: 220; R0603
R301: 10k; R0603
R311, R312: 500R; R0603
S1: 430152050826
U100: ESP8266MOD; ESP12F-SMD
X101: PINHD-1X3; 1X03
X201: M701-330442
X202: PINHD-1X6; 1X06

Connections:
+3V3: C101.1, C102.1, C201.1, C302.1, IC200.4 (!RESET), IC200.13 (VCCIO), IC300.2 (VO), R101.2, R102.2, R103.2, R211.2, R212.2, R222.2, U100.VCC, X101.3, X202.6; also elsewhere on the board
A0: R105.1, X101.2
CH1: R421.2, U100.GPIO4; also elsewhere on the board
CH2: R422.2, U100.GPIO5; also elsewhere on the board
DTR: IC200.21 (!DTR), IC201.2 (B1), IC201.4 (E2)
D_N: IC200.8 (USBDM), R202.2
D_P: IC200.7 (USBDP), R201.2, R204.1
EXTPWR: C303.1, IC301.1 (EN_N), IC301.5 (IN1), R206.1, R301.2, R311.2; also elsewhere on the board
GND: C101.2, C102.2, C201.2, C202.2, C203.2, C301.2, C302.2, C303.2, C304.2, C305.2, D311.C, D312.C, D421.C, D422.C, IC200.9 (GND), IC200.17 (GND), IC200.29 (AGND), IC200.31 (TEST), IC300.1 (GND), IC300.4 (GND), IC301.2 (GND), R104.2, R106.1, R205.1, R301.1, S1.2, S1.4, U100.GND, X101.1, X201.4 (GND), X202.1; also elsewhere on the board
IO0: IC201.3 (C2), R102.1, U100.GPIO0, X202.3
IO2: R103.1, U100.GPIO2
IO15: R104.1, U100.GPIO15
unnamed: R105.2, R106.2, U100.ADC
unnamed: R107.2, U100.TXD0
unnamed: R101.1, U100.EN
unnamed: D211.C, IC200.12 (TXLED)
unnamed: C202.1, IC200.30 (AVCC), R203.1
unnamed: D212.C, IC200.11 (RXLED)
unnamed: D211.A, R211.1
unnamed: D212.A, R212.1
unnamed: C203.1, IC200.6 (3V3OUT)
unnamed: D312.A, R312.1
unnamed: D422.A, R422.1
unnamed: L201.2, X201.1 (VCC)
unnamed: D311.A, R311.1
unnamed: D421.A, R421.1
unnamed: IC200.5 (!RESOUT), R204.2
unnamed: IC200.14 (PWRCTL), R205.2, R206.2
unnamed: D222.C, U100.GPIO13
unnamed: D222.A, R222.1
OWD: U100.GPIO16; also elsewhere on the board
RST: IC201.6 (C1), S1.1, S1.3, U100.RST, X202.2
RTS: IC200.23 (!RTS), IC201.1 (E1), IC201.5 (B2)
RX: IC200.25 (TXD), U100.RXD0, X202.4
TX: IC200.24 (RXD), R107.1, X202.5
USBD_N: R202.1, X201.2 (D-)
USBD_P: R201.1, X201.3 (D+)
USBPWR: C304.1, IC301.3 (IN2), J201.1, L201.1, R312.2
VIN: C301.1, C305.1, IC200.3 (VCC), IC200.26 (VCC), IC300.3 (VI), IC301.4 (OUT), J201.2, R203.2

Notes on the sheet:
GPIO15 GPIO0 GPIO2 1 X X SDIO/SPI WIFI 0 0 1 UART Download 0 1 1 Flash Boot
RCA-2312-020s
EspHeatController


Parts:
D411, D412: 1N4148W; SOD3715X135
K411, K412: RZ03-1A4-D005; RELAY-SPST2_5MM
Q411, Q412: BSS138; SOT23
R411, R412: 47K; R0805W
R501: 4K7; R0805W
R502: n/a; R0805W
U400: TMF 10105; TMF10
X401, X411, X412: SPT2,5/3-V-5,0
X501, X502, X503, X504, X505: PINHD-1X3; 1X03

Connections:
+3V3: R501.2, X501.3, X502.3, X503.3, X504.3, X505.3; also elsewhere on the board
AC_L: K411.2 (11), K411.5 (21), K412.2 (11), K412.5 (21), U400.2 (AC(L)), X401.1A (1), X401.1B (1)
AC_N: U400.1 (AC(N)), X401.3A (3), X401.3B (3), X411.3A (3), X411.3B (3), X412.3A (3), X412.3B (3)
AC_PE: X401.2A (2), X401.2B (2), X411.2A (2), X411.2B (2), X412.2A (2), X412.2B (2)
CH1: Q411.1 (G), R411.2; also elsewhere on the board
CH2: Q412.1 (G), R412.2; also elsewhere on the board
EXTPWR: D411.1 (C), D412.1 (C), K411.6 (A2), K412.1 (A1), U400.3 (+VOUT); also elsewhere on the board
GND: Q411.2 (S), Q412.2 (S), R411.1, R412.1, R502.1, U400.4 (-VOUT), X501.1, X502.1, X503.1, X504.1, X505.1; also elsewhere on the board
unnamed: D412.2 (A), K412.6 (A2), Q412.3 (D)
unnamed: D411.2 (A), K411.1 (A1), Q411.3 (D)
unnamed: K411.3 (24), K411.4 (14), X411.1A (1), X411.1B (1)
unnamed: K412.3 (24), K412.4 (14), X412.1A (1), X412.1B (1)
OWD: R501.1, R502.2, X501.2, X502.2, X503.2, X504.2, X505.2; also elsewhere on the board

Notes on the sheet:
EspHeatController
RCA-2312-020s

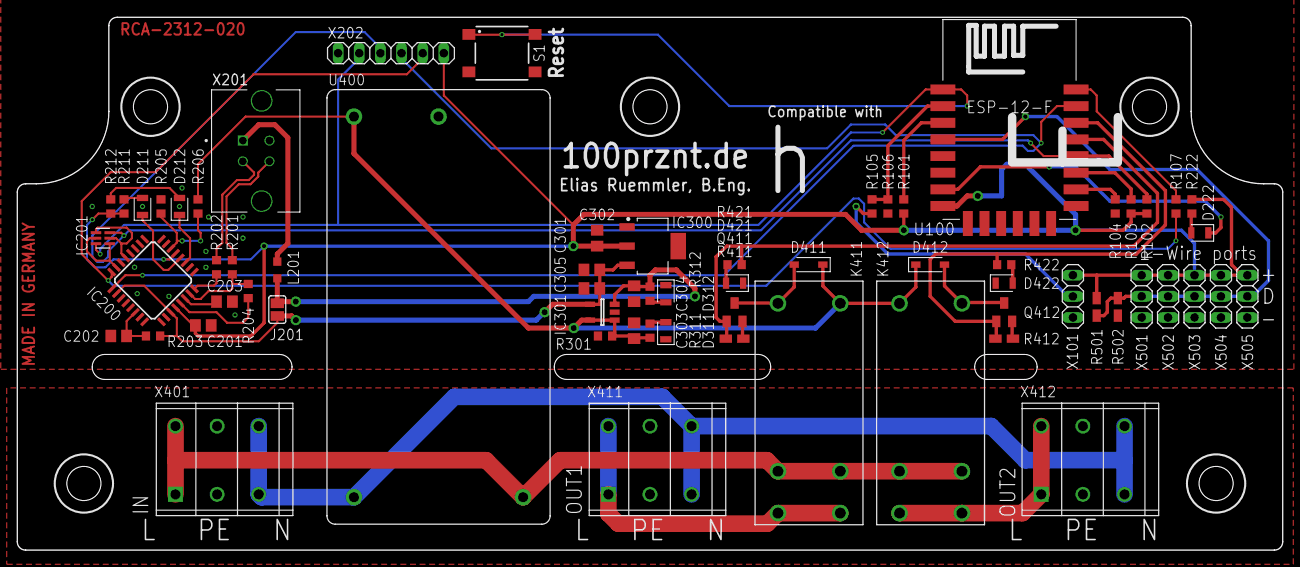
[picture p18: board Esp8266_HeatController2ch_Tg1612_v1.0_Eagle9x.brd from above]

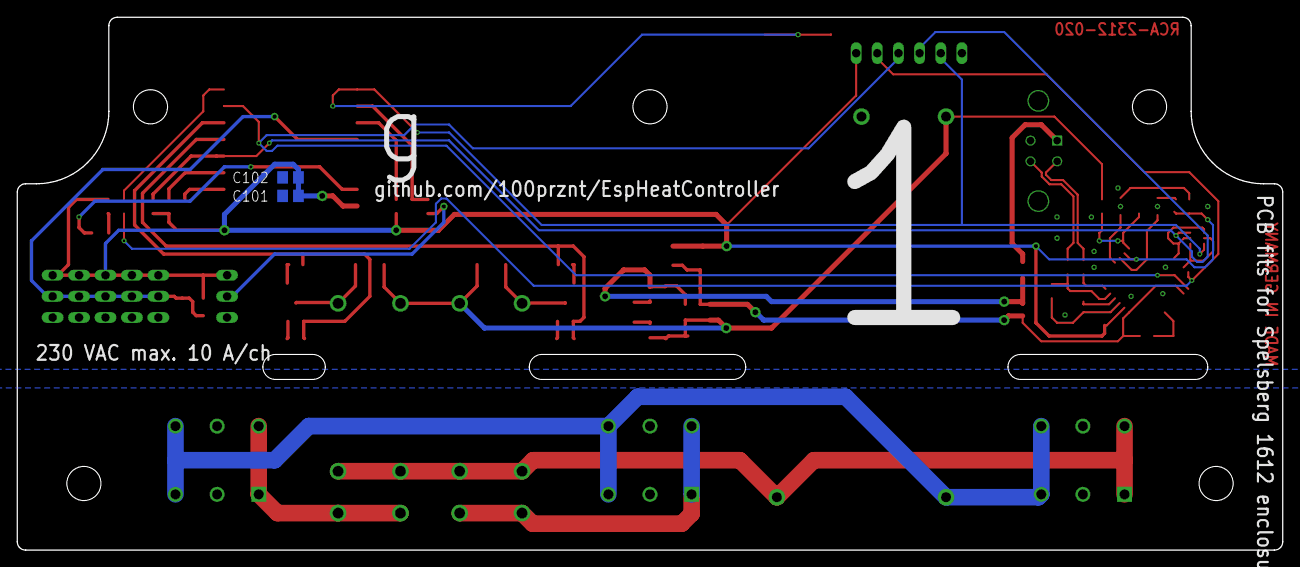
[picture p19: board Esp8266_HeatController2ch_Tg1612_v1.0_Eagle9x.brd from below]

Board: 2 copper layers, 152.0 x 64.0 mm, 68 parts (2 on the bottom side), 46 nets.

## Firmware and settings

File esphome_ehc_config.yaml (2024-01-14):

esphome:
  name: heat-controller
  friendly_name: "Heat Controller"

esp8266:
  board: esp12e

# Enable logging
logger:

# Enable Home Assistant API
api:
  encryption:
    key: <your api key>

ota:


wifi:
  ssid: !secret wifi_ssid
  password: !secret wifi_password
  # I feel better with static IPs, delete entry if not desired
  manual_ip:
    static_ip: <device ip>
    gateway: <your gateway>
    subnet: 255.255.255.0

  # Enable fallback hotspot (captive portal) in case wifi connection fails
  ap:
    ssid: "HeatController"
    password: <your password>

captive_portal:

# Status LED
status_led:
  pin:
    number: GPIO13
    inverted: true

# 1-wire config
dallas:
  - pin: GPIO16

# Relais config
switch:
  - platform: gpio
    pin:
      number: GPIO4
    id: heater_relay_1
    name: "Heater Relay CH1"
  - platform: gpio
    pin:
      number: GPIO5
    id: heater_relay_2
    name: "Heater Relay CH2"


sensor:
  - platform: uptime
    name: "HeatController Uptime"
  - platform: wifi_signal
    name: "HeatController WiFi Signal"
    update_interval: 60s
    # DS18B20 sensors
  - platform: dallas
    address: <uid of DS18B20, end with ...aa28>
    id: heater_sensor_1
    name: "Heater Sensor CH1"
  - platform: dallas
    address: <uid of DS18B20, end with ...aa28>
    id: heater_sensor_2
    name: "Heater Sensor CH2"
  # Optional sensors
  - platform: dallas
    address: <uid of DS18B20, end with ...aa28>
    id: environment_sensor
    name: "Environment Sensor"

# Controller
climate:
  - platform: bang_bang
    name: "Controller CH1"
    sensor: heater_sensor_1
    default_target_temperature_low: 20 °C
    default_target_temperature_high: 25 °C
    heat_action:
      - switch.turn_on: heater_relay_1
    idle_action:
      - switch.turn_off: heater_relay_1
  - platform: bang_bang
    name: "Controller CH2"
    sensor: heater_sensor_2
    default_target_temperature_low: 20 °C
    default_target_temperature_high: 25 °C
    heat_action:
      - switch.turn_on: heater_relay_2
    idle_action:
      - switch.turn_off: heater_relay_2

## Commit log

2023-12-11 Add cad renderings
2023-12-12 Add BOM
    [BOM_EspHeatController.csv, BOM_EspHeatController.xlsx, BOM_EspHeatController_v2.csv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]
2023-12-14 Add status LED
    [HeatController.yaml]
2023-12-15 Add controller status
    [HeatController.yaml]
2023-12-16 Add prototype
    [Einsatz_TK_PC_1813_11_tm.stl]
2023-12-21 Update case rendering
2024-01-11 Add current design
    [Esp8266_HeatController2ch_Tg1612_v1.0.brd, Esp8266_HeatController2ch_Tg1612_v1.0_Eagle9x.brd, EspHeatController_v1.0.sch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]

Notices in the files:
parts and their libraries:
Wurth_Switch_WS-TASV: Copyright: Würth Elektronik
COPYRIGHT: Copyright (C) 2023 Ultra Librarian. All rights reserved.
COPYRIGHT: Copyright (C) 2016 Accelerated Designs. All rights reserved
